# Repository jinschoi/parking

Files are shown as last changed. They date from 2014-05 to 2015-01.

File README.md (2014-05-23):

Ultrasonic Parking Aid
=======

Parking aid using the SR-04 ultrasonic distance sensor to indicate distance via LEDs. Low-power, AA battery powered, 3D printable enclosure suggestion available.

Green LED indicates go until yellow LED gets triggered at a set distance. Yellow LED blinks with a rate proportional to distance until red LED distance is crossed. LED blinking rate is implemented using TIMER1.

Low power mode is entered when no forward motion events have been detected for 5 seconds. Motion away from sensor is ignored so as not to trigger when backing away.

Libraries Required
-----

_Sleepy_ library from [jeelib](http://jeelabs.net/projects/jeelib/wiki) is used to reduce power usage when idling.

[NewPing](https://code.google.com/p/arduino-new-ping/) library is required for interfacing with the ultrasonic sensor.

Full description at [hackaday.io](http://hackaday.io/project/1218-Ultrasonic-Parking-Aid-without-Arduino).

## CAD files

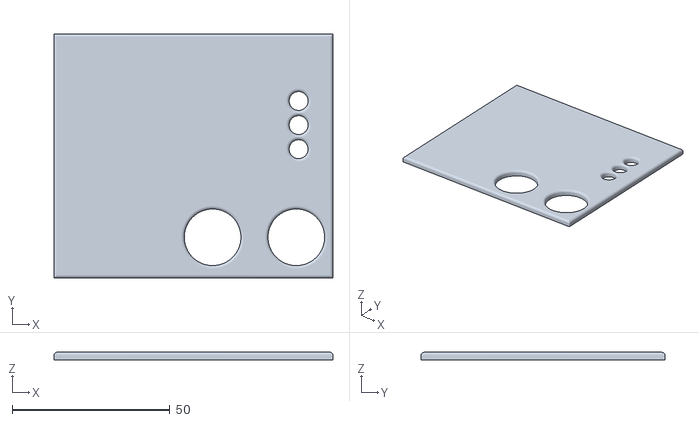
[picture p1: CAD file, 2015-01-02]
Enclosure/lid.stl
88.3 x 77.2 x 2.40

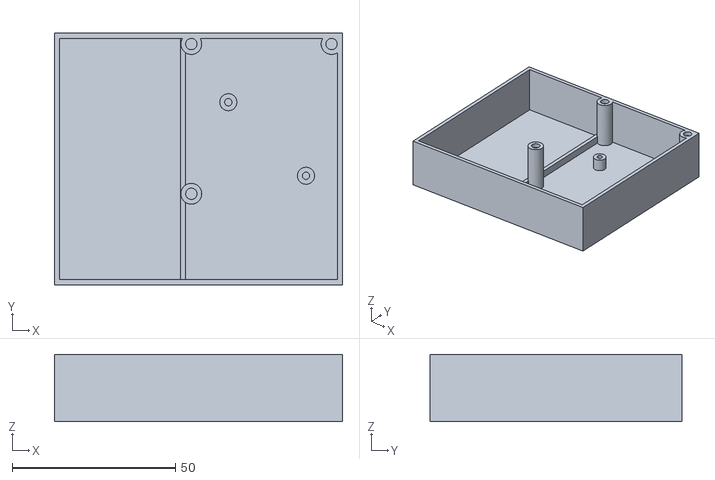
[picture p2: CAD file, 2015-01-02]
Enclosure/box.stl
88.3 x 77.2 x 20.6

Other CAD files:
Enclosure/parking.f3d

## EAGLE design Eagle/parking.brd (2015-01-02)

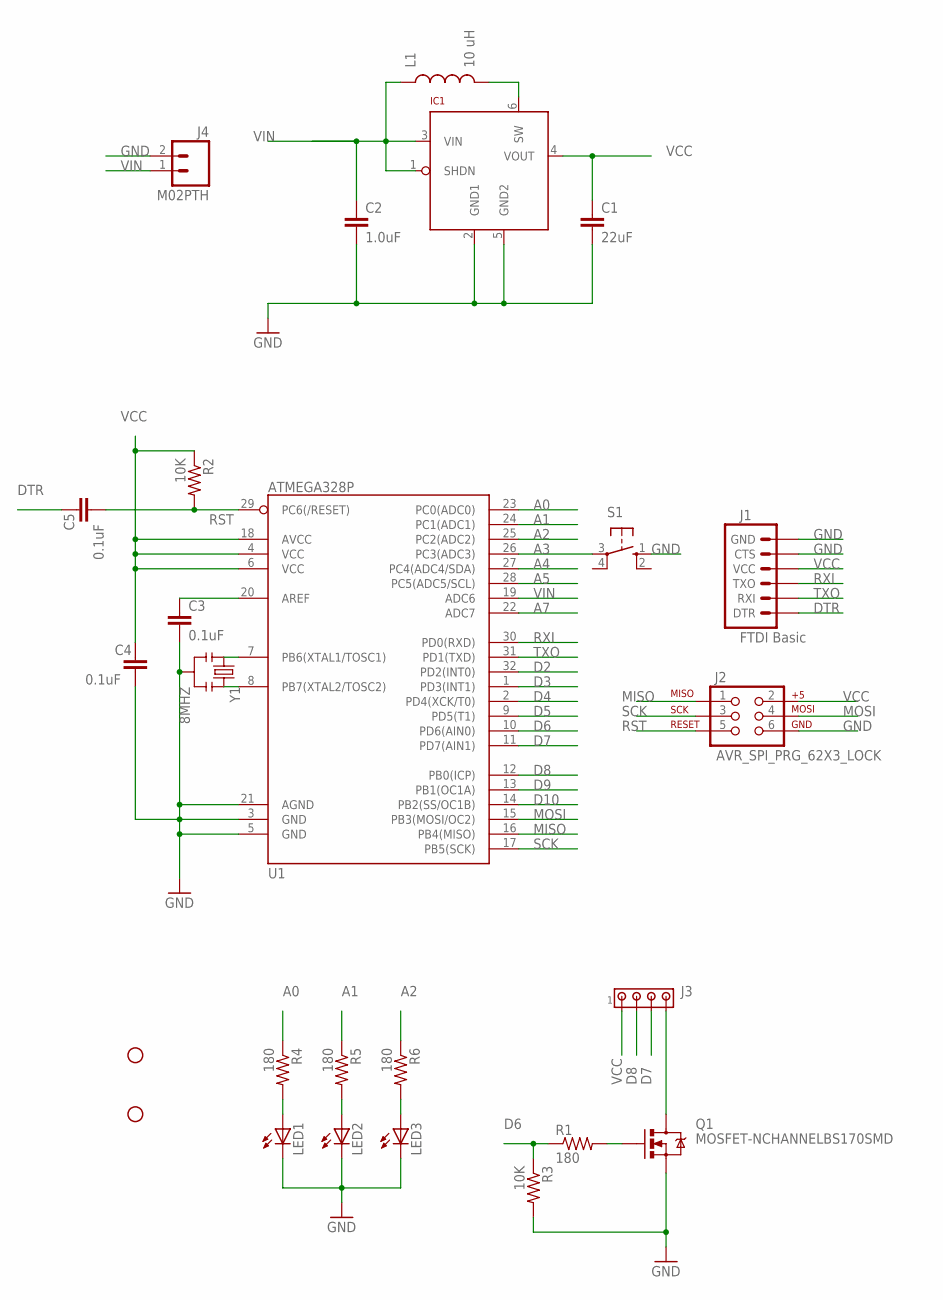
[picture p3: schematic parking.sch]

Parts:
C1: 22uF; 0805
C2: 1.0uF; 0805
C3, C4, C5: 0.1uF; 0805
IC1: LTC3525; SC70
J1: FTDI Basic; 1X06
J2: AVR_SPI_PRG_62X3_LOCK; 2X3_LOCK
J3: MTA04-100; 10X04MTA
J4: M02PTH; 1X02
L1: 10 uH; 1210
LED1, LED2, LED3: LED5MM
Q1: MOSFET-NCHANNELBS170SMD; SOT23
R1, R4, R5, R6: 180; 0805
R2, R3: 10K; 0805
S1: 10-XX; B3F-10XX
STANDOFF1, STANDOFF2: STAND-OFF
U1: ATMEGA328P; TQFP32-08
Y1: 8MHZ; RESONATOR-SMD

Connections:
A0: R4.1, U1.23 (PC0(ADC0))
A1: R5.1, U1.24 (PC1(ADC1))
A2: R6.1, U1.25 (PC2(ADC2))
A3: S1.3, U1.26 (PC3(ADC3))
A4: U1.27 (PC4(ADC4/SDA))
A5: U1.28 (PC5(ADC5/SCL))
A7: U1.22 (ADC7)
D2: U1.32 (PD2(INT0))
D3: U1.1 (PD3(INT1))
D4: U1.2 (PD4(XCK/T0))
D5: U1.9 (PD5(T1))
D6: R1.1, R3.1, U1.10 (PD6(AIN0))
D7: J3.3, U1.11 (PD7(AIN1))
D8: J3.2, U1.12 (PB0(ICP))
D9: U1.13 (PB1(OC1A))
D10: U1.14 (PB2(SS/OC1B))
DTR: C5.1, J1.1 (DTR)
GND: C1.2, C2.2, C3.2, C4.2, IC1.2 (GND1), IC1.5 (GND2), J1.5 (CTS), J1.6 (GND), J2.6, J4.2, LED1.K (C), LED2.K (C), LED3.K (C), Q1.2 (S), R3.2, S1.1 (S), U1.3 (GND), U1.5 (GND), U1.21 (AGND), Y1.2
MISO: J2.1, U1.16 (PB4(MISO))
MOSI: J2.4, U1.15 (PB3(MOSI/OC2))
unnamed: U1.8 (PB7(XTAL2/TOSC2)), Y1.3
unnamed: U1.7 (PB6(XTAL1/TOSC1)), Y1.1
unnamed: IC1.6 (SW), L1.2
unnamed: C3.1, U1.20 (AREF)
unnamed: LED1.A, R4.2
unnamed: LED2.A, R5.2
unnamed: LED3.A, R6.2
unnamed: J3.4, Q1.3 (D)
unnamed: Q1.1 (G), R1.2
RST: C5.2, J2.5, R2.2, U1.29 (PC6(/RESET))
RXI: J1.3 (TXO), U1.30 (PD0(RXD))
SCK: J2.3, U1.17 (PB5(SCK))
TXO: J1.2 (RXI), U1.31 (PD1(TXD))
VCC: C1.1, C4.1, IC1.4 (VOUT), J1.4 (VCC), J2.2, J3.1, R2.1, U1.4 (VCC), U1.6 (VCC), U1.18 (AVCC)
VIN: C2.1, IC1.1 (SHDN), IC1.3 (VIN), J4.1, L1.1, U1.19 (ADC6)

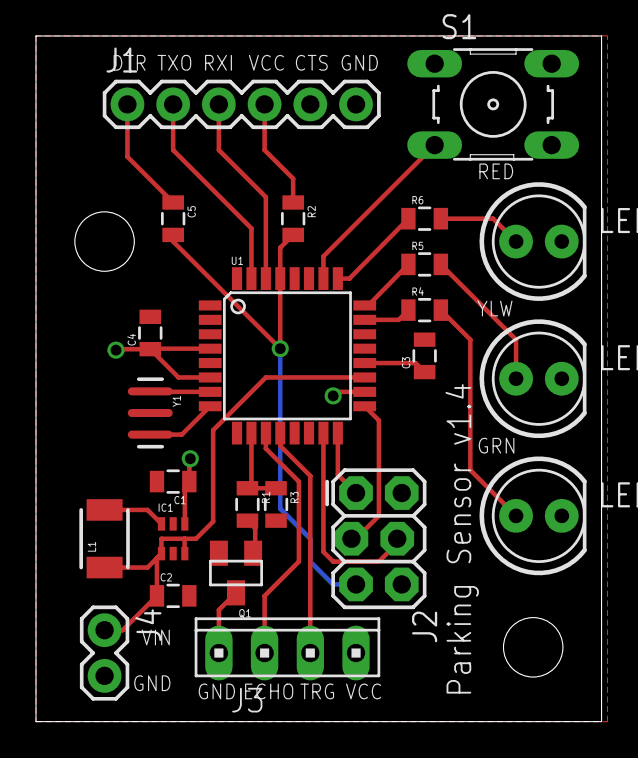
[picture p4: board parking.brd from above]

Board: 2 copper layers, 31.4 x 38.1 mm, 26 parts (0 on the bottom side), 26 nets.

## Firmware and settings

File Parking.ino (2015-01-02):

// Must have DISABLE_ONE_PIN set to true! Not the default: edit NewPing.h to set it.
#include <NewPing.h>
#include <JeeLib.h>
#include <EEPROM.h>
#include <avr/interrupt.h>

// Pins.
#define RED A2
#define YELLOW A1
#define GREEN A0

// States
// Car is not present.
#define WAITING 0
// Car is present and moving.
#define PARKING 1
// Car is present and not moving.
#define PARKED 2

// Pins for SR04.
#define PING_ENABLE 6
#define ECHO_PIN 7
#define TRIGGER_PIN 8

// Minimum trigger distances in cm.
#define YELLOW_DIST 40
#define GREEN_DIST 150
#define MAX_DIST 500

// Push button input pin
#define BUTTON A3

// Input voltage pin
#define VIN_PIN A6

// 8000000/256/1000
#define TICKS_PER_MS 31.25

// Flash rates in ticks (half periods).
#define FASTEST_FLASH_RATE (10 * TICKS_PER_MS)
#define SLOWEST_FLASH_RATE (500 * TICKS_PER_MS)

// #define DEBUG

#ifdef DEBUG
  #define sleep delay
#else
  #define sleep Sleepy::loseSomeTime
#endif

NewPing sonar(TRIGGER_PIN, ECHO_PIN, MAX_DIST);
uint16_t ticks = 0xffff;
int state;
int range;
int last_distance;
int idle_count;
int no_detect_count;
int cm;
float vin;

// Return the requested number of digits of the mantissa as a char. Only works for digits up to 2.
char decToInt(float f, int digits) {
  return round(abs(f - (int) f) * pow(10, digits));
}

void blink(int pin, int times)
{
  for (int i = 0; i < times; i++) {
    digitalWrite(pin, HIGH);
    sleep(25);
    digitalWrite(pin, LOW);
    sleep(200);
  }
}

void read_vin() {
  vin = analogRead(VIN_PIN) / 1023.0 * 5.0;
}

void report_vin() {
  read_vin();
#ifdef DEBUG
  Serial.print("VIN: ");
  Serial.println(vin);
#endif

  blink(RED, vin);
  sleep(200);
  blink(GREEN, decToInt(vin, 1));
}

int lastButtonState = HIGH;
int yellowDist;

void setup() {
#ifdef DEBUG
  Serial.begin(115200);
#endif

  pinMode(RED, OUTPUT);
  pinMode(YELLOW, OUTPUT);
  pinMode(GREEN, OUTPUT);
  pinMode(PING_ENABLE, OUTPUT);

  pinMode(BUTTON, INPUT);
  digitalWrite(BUTTON, HIGH);

  yellowDist = EEPROM.read(0);
  if (yellowDist == 255)
    yellowDist = YELLOW_DIST;

  report_vin();

  // Set up TIMER1.
  TCCR1A = B00000000;
  TCCR1B = B00001100; // CTC mode, 256 prescaler, for a max period of ~2s at 8 Mhz.

  state = WAITING;
  range = 0;
  last_distance = MAX_DIST;
  idle_count = 0;
  no_detect_count = 0;
  cm = 0;
}

// Calculate a flash rate based on the given distance. Only called for yellow state.
inline uint16_t ticks_for_dist(int cm) {
  return FASTEST_FLASH_RATE + (SLOWEST_FLASH_RATE - FASTEST_FLASH_RATE) * (cm - yellowDist) / (GREEN_DIST - yellowDist);
}

void enable_sr04() {
  // Reset the trigger pin mode to output.
  pinMode(TRIGGER_PIN, OUTPUT);

  // Connect GND to the sensor.
  digitalWrite(PING_ENABLE, HIGH);

  // Various data sheets exhort you connect GND before VCC, but never say what will happen if you don't.
  // What appears to happen is that the echo pin stays high, and you get a short read on the first ping.
  // A sacrificial ping after a short delay after power up appears to make everything happy again.
  delay(20);
  sonar.ping();

  // Enforce a settling delay.
  delay(29);
}

void disable_sr04() {
  digitalWrite(PING_ENABLE, LOW);
  // As well as disconnecting GND with a low side MOSFET, we have to disconnect
  // the trigger pin, or the sensor will find ground through it and remain powered up.
  pinMode(TRIGGER_PIN, INPUT);
}

int ping() {
  enable_sr04();

  int uS = sonar.ping_median(3);
  cm = sonar.convert_cm(uS);

#ifdef DEBUG
  Serial.print(cm);
  Serial.print(" ");
  Serial.print(last_distance);
  Serial.print(" ");
  Serial.print(state);
  Serial.print(" ");
  Serial.println(idle_count);
#endif

  disable_sr04();
  return cm;
}

int ping_and_blink(int pin) {
  ping();
  digitalWrite(pin, HIGH);
  sleep(25);
  digitalWrite(pin, LOW);
}

void updateYellowDist() {
  int cm = ping();
  if (cm > 0) {
    EEPROM.write(0, cm);
    yellowDist = cm;
  }
}

void loop() {
#ifndef DEBUG
  // Check battery status. vin is set on report_vin at setup and in the PARKED state, and during the WAITING loop.
  if (vin < 2.0 && 0) {
    // Each cell is < 1V.
    blink(RED, 3);
    sleep(10000);
    read_vin();
    return;
  }
#endif  

  int buttonState = digitalRead(BUTTON);
  if (lastButtonState == HIGH && buttonState == LOW) {
    updateYellowDist();
  }
  lastButtonState = buttonState;

  if (state == WAITING) {
    sleep(1000);

    read_vin();
    ping_and_blink(GREEN);

    if (cm == 0) return; // Keep waiting.

    // Got a return.
    state = PARKING;
    last_distance = MAX_DIST;
    return;
  }

  if (state == PARKED) {
    sleep(60000);

    // If it's been 5 minutes since we've detected a car, go to the waiting state.
    if (no_detect_count > 5) {
      state = WAITING;
      no_detect_count = 0;
      return;
    }

    // ping_and_blink(RED);
    report_vin();
    ping();

    if (cm == 0) {
      no_detect_count++;
      return;
    }
    no_detect_count = 0;

    if (cm < last_distance - 5 || cm > last_distance + 5) {
      // Car not where we last saw it, back to parking state.
      state = PARKING;
    }

    last_distance = cm;
  }

  if (state == PARKING) {
    delay(100);

    // If we have not detected a car in 5s, go back to the waiting for car state.
    if (no_detect_count > 50) {
      state = WAITING;
      no_detect_count = 0;
      idle_count = 0;
      digitalWrite(RED, LOW);
      stop_blinking();
      digitalWrite(GREEN, LOW);
      return;
    }

    if (idle_count > 100) { // 10s of no forward events; we're parked.
      state = PARKED;
      no_detect_count = 0;
      idle_count = 0;
      digitalWrite(RED, LOW);
      stop_blinking();
      digitalWrite(GREEN, LOW);
      return;
    }

    ping();

    if (cm == 0) {
      no_detect_count++;
      return;
    }
    no_detect_count = 0;

    // Only take into account forward motion for purposes of idle detection.
    if (cm >= last_distance - 3) { // 3 cm slop factor.
      last_distance = max(last_distance, cm);
      idle_count++;
    } else {
      last_distance = cm;
      idle_count = 0;
    }

    if (cm >= GREEN_DIST) { // GREEN
      if (range == YELLOW) stop_blinking();
      if (range == RED) digitalWrite(RED, LOW);
      if (range != GREEN) {
        range = GREEN;
        digitalWrite(GREEN, HIGH);
      }
    } else if (cm < yellowDist) { // RED
      if (range == YELLOW) stop_blinking();
      if (range == GREEN) digitalWrite(GREEN, LOW);
      if (range != RED) {
        range = RED;
        digitalWrite(RED, HIGH);
      }
    } else { // YELLOW
      if (range == GREEN) digitalWrite(GREEN, LOW);
      if (range == RED) digitalWrite(RED, LOW);
      ticks = ticks_for_dist(cm);
#ifdef DEBUG
      Serial.print("ticks: ");
      Serial.println(ticks);
#endif    

      if (range != YELLOW) {
        range = YELLOW;
        start_blinking();
      }
    }
  }
}

// Start the yellow LED blinking at a rate inversely proportional to the distance.
void start_blinking() {
  // Start with the yellow on.
  digitalWrite(YELLOW, HIGH);

  // Clear match flag.
  TIFR1 |= _BV(OCF1A);

  // 16 bit register, so disable interrupts for safety.
  uint8_t sreg = SREG;
  cli();
  OCR1A = ticks; // set match count
  SREG = sreg;  

  TCNT1 = 0; // reset clock
  TIMSK1 |= _BV(OCIE1A); // enable timer interrupts
}

void stop_blinking() {
  TIMSK1 &= ~_BV(OCIE1A); // disable timer interrupts
  digitalWrite(YELLOW, LOW);
}

ISR(TIMER1_COMPA_vect) {
  // Toggle yellow LED.
  digitalWrite(YELLOW, digitalRead(YELLOW) ^ 1);

  // Set next period based on distance.
  OCR1A = ticks;
}

// Needed for Sleepy library.
ISR(WDT_vect) { Sleepy::watchdogEvent(); }

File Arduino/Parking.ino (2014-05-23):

#include <NewPing.h>
#include <JeeLib.h>
#include <avr/interrupt.h>

// Pins. Also used as state machine states.
#define RED A2
#define YELLOW A1
#define GREEN A0

// Not a pin, just a state.
#define SLEEP 0

// Pins for SR04.
#define TRIGGER_PIN 8
#define ECHO_PIN 7

// Minimum trigger distances in cm.
#define YELLOW_DIST 30
#define GREEN_DIST 100
#define MAX_DIST 500

// 8000000/256/1000
#define TICKS_PER_MS 31.25

// Flash rates in ticks (half periods).
#define FASTEST_FLASH_RATE (10 * TICKS_PER_MS)
#define SLOWEST_FLASH_RATE (500 * TICKS_PER_MS)

// #define DEBUG

NewPing sonar(TRIGGER_PIN, ECHO_PIN, MAX_DIST);
uint16_t ticks = 0xffff;
int state;
int last_distance;
int idle_count;

void setup() {

#ifdef DEBUG
  Serial.begin(115200);
#endif

  pinMode(RED, OUTPUT);
  pinMode(YELLOW, OUTPUT);
  pinMode(GREEN, OUTPUT);

  // Set up TIMER1.
  TCCR1A = B00000000;
  TCCR1B = B00001100; // CTC mode, 256 prescaler, for a max period of ~2s at 8 Mhz.

  state = SLEEP;
  last_distance = MAX_DIST;
  idle_count = 0;
}

// Calculate a flash rate based on the given distance. Only called for yellow state.
inline uint16_t ticks_for_dist(int cm) {
  return FASTEST_FLASH_RATE + (SLOWEST_FLASH_RATE - FASTEST_FLASH_RATE) * (cm - YELLOW_DIST) / (GREEN_DIST - YELLOW_DIST);
}

void loop() {
  if (state == SLEEP) {
#ifdef DEBUG
    delay(2000);
#else
    Sleepy::loseSomeTime(2000);
#endif
  }
  else delay(100);

  int uS = sonar.ping_median(3);
  int cm = sonar.convert_cm(uS);

#ifdef DEBUG
  Serial.print(cm);
  Serial.print(" ");
  Serial.print(last_distance);
  Serial.print(" ");
  Serial.print(state);
  Serial.print(" ");
  Serial.println(idle_count);
#endif

  // Go to power saving if we haven't had any interesting events in a while.
  if (idle_count > 50 && state != SLEEP) { // 5s if not already in sleep mode
    state = SLEEP;
    digitalWrite(RED, LOW);
    stop_blinking();
    digitalWrite(GREEN, LOW);
    return;
  }

  // Ignore motion away, with a little slop factor thrown in.
  if (cm >= last_distance - 2) {
    idle_count++;
    last_distance = max(last_distance, cm);
    return;
  }

  // Ignore null detects.
  if (cm == 0) {
    idle_count++;
    last_distance = MAX_DIST;
    return;
  }

  last_distance = cm;
  idle_count = 0;

  if (cm >= GREEN_DIST) { // GREEN
    if (state == YELLOW) stop_blinking();
    if (state == RED) digitalWrite(RED, LOW);
    if (state != GREEN) {
      state = GREEN;
      digitalWrite(GREEN, HIGH);
    }
  } else if (cm < YELLOW_DIST) { // RED
    if (state == YELLOW) stop_blinking();
    if (state == GREEN) digitalWrite(GREEN, LOW);
    if (state != RED) {
      state = RED;
      digitalWrite(RED, HIGH);
    }
  } else { // YELLOW
    if (state == GREEN) digitalWrite(GREEN, LOW);
    if (state == RED) digitalWrite(RED, LOW);

    ticks = ticks_for_dist(cm);
#ifdef DEBUG
    Serial.println("ticks: ");
    Serial.println(ticks);
#endif    

    if (state != YELLOW) {
      state = YELLOW;
      start_blinking();
    }
  }
}

// Start the yellow LED blinking at a rate inversely proportional to the distance.
void start_blinking() {
  // Start with the yellow on.
  digitalWrite(YELLOW, HIGH);

  // Clear match flag.
  TIFR1 |= _BV(OCF1A);

  // 16 bit register, so disable interrupts for safety.
  uint8_t sreg = SREG;
  cli();
  OCR1A = ticks; // set match count
  SREG = sreg;  

  TCNT1 = 0; // reset clock
  TIMSK1 |= _BV(OCIE1A); // enable timer interrupts
}

void stop_blinking() {
  TIMSK1 &= ~_BV(OCIE1A); // disable timer interrupts
  digitalWrite(YELLOW, LOW);
}

ISR(TIMER1_COMPA_vect) {
  // Toggle yellow LED.
  digitalWrite(YELLOW, digitalRead(YELLOW) ^ 1);

  // Set next period based on distance.
  OCR1A = ticks;
}

// Needed for Sleepy library.
ISR(WDT_vect) { Sleepy::watchdogEvent(); }

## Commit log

2014-05-23 Added project files.
    [case.stl, lid.stl, parking.brd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]
2014-05-23 Moved Arduino sketch to toplevel.
2014-05-25 Revised enclosure.
    [case.stl, lid.stl]
2014-05-26 Fixed misrouted trace for bypass capacitor.
    [parking.brd]
2014-06-10 Changed resonator footprint, modified ping sensor VCC to be switched from a pin to save power.
    [parking.brd, parking.sch]
2014-07-01 Added low side MOSFET switch to power down the sensor.
    [parking.brd, parking.sch]
2014-07-19 Updated sketch for revision 1.3 of the board, with MOSFET sensor switch and VIN trace.
2014-07-19 Fixed stupid battery voltage reading bug.
    [Parking.ino]
2014-07-20 Updated enclosure files for 1.3
    [case.stl, lid.stl]
2014-07-25 Added alternative side-by-side enclosure design files.
    [battery-flat.stl, case-flat.stl, lid-flat.stl]
2015-01-02 Revision 1.4 of the board. Includes a pushbutton to calibrate red light distance.
    [battery-flat.stl, box.stl, case-flat.stl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]

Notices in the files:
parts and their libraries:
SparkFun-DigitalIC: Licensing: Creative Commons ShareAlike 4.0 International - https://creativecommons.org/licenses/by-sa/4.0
